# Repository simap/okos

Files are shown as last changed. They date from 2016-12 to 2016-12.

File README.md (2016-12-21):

One Kilobyte Operating System (OKOS)
================

Tiny OS for 1kB challenge.

Blurring the line between embedded system and general purpose computer. Inspired by all those wizardly tricks that brought computing to the masses on limited hardware.

OKOS is an operating system that allows the user to edit text or assembly source files code, assemble these into executables, and run their programs.

Features
---

* Runs on a PIC18f25k50, the MCU in the HaD SuperCon Badge!
* Display driver and API
	* Supports SSD1306 OLED display with 128x64 pixels over i2c, with the font included that is 32x8 characters.
	* Minimal 3x5 tiny font (remember original Apple ][ uppercase only font?)
	* Line buffered text drawing api (write whole row at a time)
	* Optional lowercase font, with descender support 3x5.5! But it takes 10 more bytes to support :(
	* Check out git history for a full ascii compatible font + display driver in less than 400 bytes.
* Filesystem (if you can call it that)
	* Actually just chopping 32k flash into 16 * 2k files.
	* 15 files available to user numbered 1-F. Can be either text files or programs.
* Touch keyboard
	* Chainable capacitive keyboard controller in 106.75 bytes.
	* Can scan up to 256 keys, though OKOS uses only 44 w/ 6 chained controllers.
	* Normal sized sized qwerty keyboard (keyboard and controller Eagle files included)
* Very basic command line interface lets you edit files, assemble them, and run programs
* Minimal instruction set assembler for the PIC MCU
	* What kind of OS doesn't let you write code?!?
	* Minimal, but workable, instruction set support.
	* Writes executable machine code into another file. Not interpreted!
* Visual Text Editor
	* Hopefully better than edlin
* Run
	* User program takes over
	* Core API available
	* User program interrupts supported (ISR vector depends on what program is running)
* OKOS is just ok because OKOS is just OK.

One Kilobyte Breakdown
-------

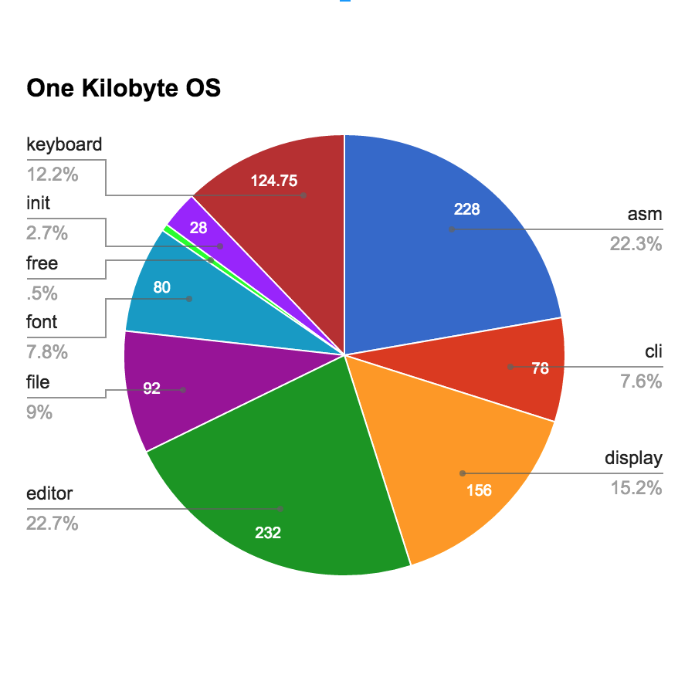
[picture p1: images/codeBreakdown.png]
Code usage by category


Visual Text Editor
================

Edit a text file with `e <file>` e.g. `e 1` to edit the text file `1`.

The current line will have an arrow in the left-side gutter. Arrow keys are not supported, but instead the keypad 8 (up) and 2 (down) keys are used for navigating. You can scroll through the file with these arrow keys.

The cursor is always at the end of the line. You can delete with backspace (including over newlines), or type to add more characters to a line. Pressing enter will append a newline.

Save the file with the `F1` key.

Assembler
================

Assemble a file with `a <source> <out>` e.g. `a 1 2` assembles source code in file `1` writing the executable to file `2`.

Minimal usable PIC instruction set.

3 character mnemonics to save space.

* `;` for comments, can be anywhere
* `.` on a line alone to end the file/parsing. **REQUIRED**

User ISR starts at offset **`0x04`** or. This gives you enough room to jump away at the start of your program.
Boilerplate program with an ISR:

```
bra 0012 ; jump past ISR
; insert your ISR code here
; ...
bra 000b ; execute a return
; at address 12. insert your code here
. ; EOF
```

User memory starts at address 0x3A, with the line buffer at 0x1A, anything before that is needed by the core API. If you don't use the API, feel free to reclaim this memory! Note that if you use ISRs, address 0x00 controls which file block the ISR jumps to.

Unfortunately, there wasn't enough room to support labels.

#### Instruction Set

| PIC instruction | short mnemonic | args | notes |
| --- | --- | --- | --- |
| bcf | bcf | f, b | 1 instruction |
| bsf | bsf | f, b | 1 instruction |
| btfsc | btc | f, b | 1 instruction |
| btfss | bts | f, b | 1 instruction |
| movlw | mvl | k | 1 instruction |
| movwf | mvw | f | 1 instruction |
| movf | mvf | f, d | 1 instruction |
| addwf | add | f, d | 1 instruction |
| andwf | and | f, d | 1 instruction |
| iorwf | ior | f, d | 1 instruction |
| xorwf | xor | f, d | 1 instruction |
| rlcf | rlc | f, d | 1 instruction |
| rrcf | rrc | f, d | 1 instruction |
| goto | bra | k | 2 instructions<br>target address is doubled. Think of them as instruction word addresses instead of byte addresses. File 1 starts at `0x400`|
| call | cal | k | 2 instructions. Same addressing as goto |
| return | - | - | NOT IMPLEMENTED<br>Use **`bra b`** |

**NOTE** return is not implemented, but a return instruction is placed at address 0x16 (word 0xb), jumping there will effect a return.

#### Core API

These API are available and potentially useful to user written programs.

| Routine | address | cal address | Notes |
| --- | --- | --- | --- |
| return_bra | 0x000016 | 000B | Use this to return. |
| oledDrawFlushLine | 0x00012c | 0096 | write up to 32 characters to 0x1A. Filled with spaces on return. | 
| readKey | 0x00015c | 00AE | Waits for keypress, returns character in WREG, also in 0x03. Blocks until key is pressed. You probably want to write something better in an ISR. |
| openFile | 0x0002d2 | 0169 | Sets up TBLPTR for reading/writing to the given file in WREG |
| fputc | 0x000294 | 014A | Writes a byte in WREG, flushing pages as needed |
| flushLastPage | 0x0002a2 | 0151 | If bit 0 in memory 0x01 is set, you need to call this once to flush the last page, since pages are only flushed by fputc in 64b increments. |

Running Programs
================

Once you've written and assembled an executable, you can run with with `r <file>` e.g. `r 2` to run file `2`.

Your program takes over until the computer is reset.

In main.asm, a define can be set to write an example program to flash. Both the assembler version and the text file are included.

Hardware
================

OKOS was written on and designed to run on the PIC MCU in the HaD SuperCon badge. The badge exposes a few GPIO, with i2c support. 

Originally OKOS was written with PS2 keyboard support, though later this was replaced with a capacitive touch keyboard so that all code could be accounted for. A define can be set to re-enable PS2 keyboard support without having to make your own keyboard hardware.

The keyboard is regular sized, and the solder joints were sanded down for a smooth surface before it was coated with polyurethane. It has a nice feel to it!

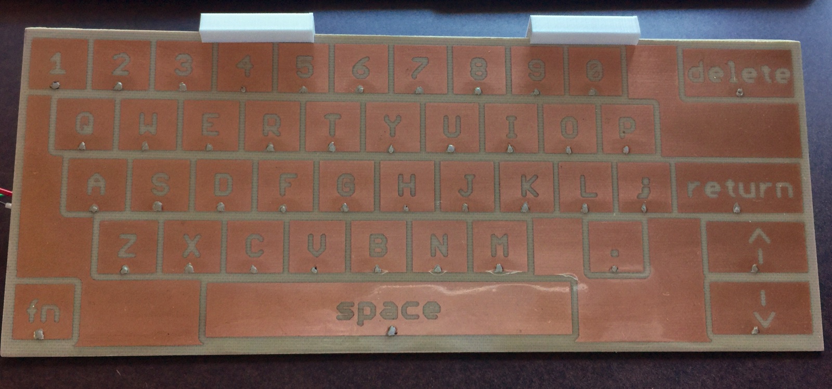
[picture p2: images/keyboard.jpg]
Touch qwerty keyboard


The capacitive touch keyboard is scanned with a handful of daisy chained pic16f1574 wired to a qwerty touch keyboard. Each runs exactly the same copy of code and scans 8 keys, passing messages from other controllers in the chain.

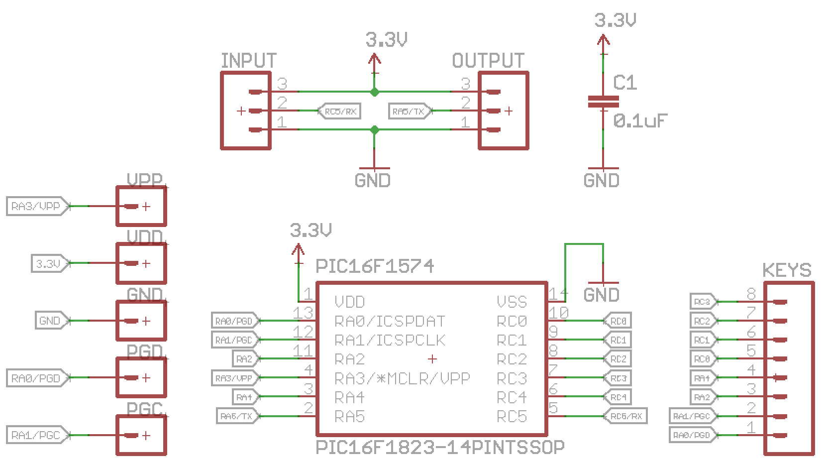
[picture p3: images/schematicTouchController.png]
Schematic of touch controller


6 of these controllers chained together make up the keyboard controller. 
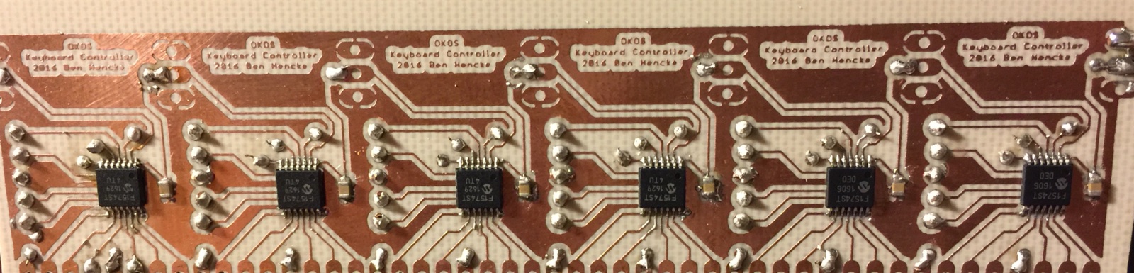
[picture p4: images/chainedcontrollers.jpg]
Assembled controller chain

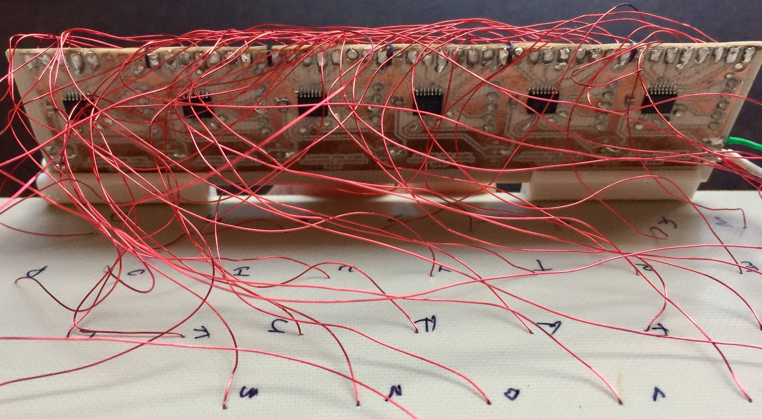
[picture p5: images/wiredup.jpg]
Controller chain attached to keyboard


There is also a board for placing the OLED display and doing level shifting to support PS2 keyboards. This connects to the expansion port on the badge.
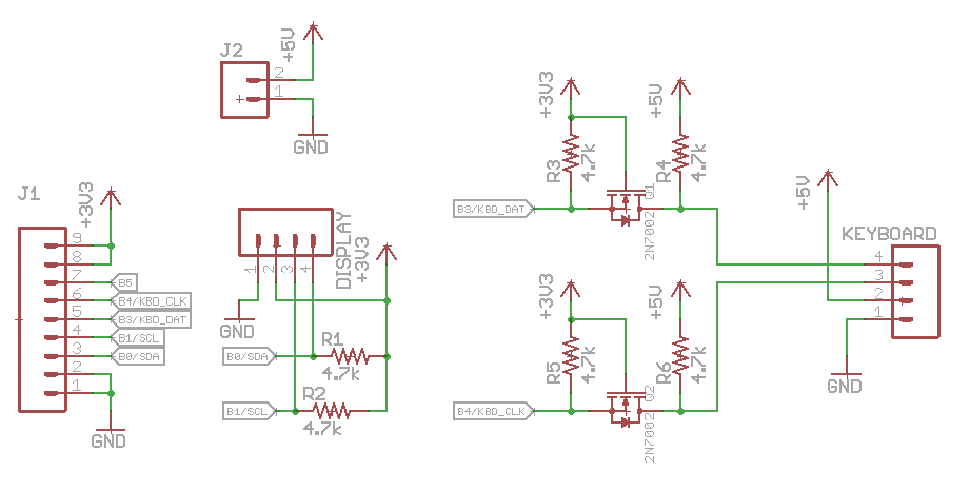
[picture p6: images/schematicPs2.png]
Schematic diagram


Notes
================

### Character set

Supports 0-9, a-z, period, semicolon, space, newline, esc, F1, backspace, Keypad 2,8,6

Maps directly to hex, such that 0x0 => '0', 0xa => 'A'.

### keyboard

Supports PS2 keyboards, decode scancodes into character set.

* simple protocol
* can ignore keyup. 
* ignore most special keys.

### filesystem

* pic18f25k50 has 32k flash. Split into 16 "files" of 2k each. file 0 (half of it anyway) contains OKOS.
* There wasn't enough space to do much else

### display

* the 128x64 oled needs very little setup.
* could get 10 lines of text (+ 4 pixels spare), but requires extra bit shifting. 8 lines of 8 pixels is easy w/ the displays 8 bit tall row x 128 segments.
* Each font face is 15 bits. To save space, only uppercase is supported, though the code can support lowercase and even use the 16th bit to shift down for lowercase descenders with 10 more bytes of code.
* Originally it rendered characters on the fly and send to display, but positioning and redraw was difficult. Now uses a line buffer and draws one row at a time, and is faster.

### MCU

Microchip PIC18f25k50

* uses 16-bit instruction words, and can store 2-8bit bytes per word easily.
* has 32k of flash, leaving plenty for filesystem
* Has almost enough RAM to fit entire 2k "file" into memory. 
* Also happens to be in the HaD SuperCon Badge.

### A Comment on Interrupts

First of all, I love interrupts. It's why I added some hooks that allow user programs to have ISRs at all.

However, when I went to write the i2c display stuff and the keyboard handling code, the ISR quickly consumed a lot of program space just saving and restoring registers. On top of that, the state machine, timers/timeouts, checking flags, etc. all took more space than I had.

1K Mapfile evidence
========

The main controller OS program code weighs in at 912 bytes. The keyboard controller is 106.75 bytes (61 14-bit instructions).

Main controller & OS
--------

[Full mapfile here](okos.X/dist/default/production/okos.X.production.map)

Note that configuraton fuses on the main PIC are located at `0x300000` and are not actually program flash, the programm usage calculation is flawed! Main controller program memory ends (and includes) address `0x00038f` - 912 bytes. Also `.cinit` is a bug/feature of MPLAB that could be removed with a custom linker file or by switching to absolute mode (as was done for the keyboard controller).

Here's the relevant bit from the mapfile:

```
                              Program Memory Usage 
                               Start         End      
                           ---------   ---------      
                            0x000000    0x00038f      
                            0x300000    0x300003      
                            0x300005    0x300006      
                            0x300008    0x30000d      
            924 out of 33048 program addresses used, program memory utilization is 2%
```

Keyboard controller
--------

[Full mapfile here](keyboard.X/dist/default/production/keyboard.X.production.map)

Note that configuraton fuses on the keyboard controller PIC are located at `0x008007` and are not actually program flash, the programm usage calculation is flawed! The program memory ends (and includes) address `0x00003c ` - 61 x 14-bit instructions or 854 bits = 106.75 bytes.

Here's the relevant bit from the mapfile:

```
                              Program Memory Usage 
                               Start         End      
                           ---------   ---------      
                            0x000000    0x00003c      
                            0x008007    0x008008      
            63 out of 4103 program addresses used, program memory utilization is 1%
```

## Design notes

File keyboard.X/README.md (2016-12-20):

OKOS Keyboard
==================

daisy chain pic16f1574 w/ uarts.
each chip reads 8 ADC touch pads
uart read, add 8, forward
arrange pads to align with character set

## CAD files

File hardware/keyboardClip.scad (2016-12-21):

keyboardW = 224;
keyboardH = 90;
controllerW = 126;
controllerH = 40;
extraH = 4;

gapW = (keyboardW-controllerW)/2;

difference() {
    translate([-keyboardW/2,0, controllerH + extraH])
    rotate([-asin((controllerH+extraH)/keyboardH),0,0]) 
    difference() {
        union() {
            rotate([asin((controllerH+extraH)/keyboardH),0,0]) 
            translate([gapW,-2.5,-9])
            cube([controllerW , 7, 14]);
        }
        #cube([keyboardW, keyboardH, 2], center=false);
    }

    translate([-controllerW/2,0,0])
    #cube([controllerW, 2, controllerH], center=false);
}

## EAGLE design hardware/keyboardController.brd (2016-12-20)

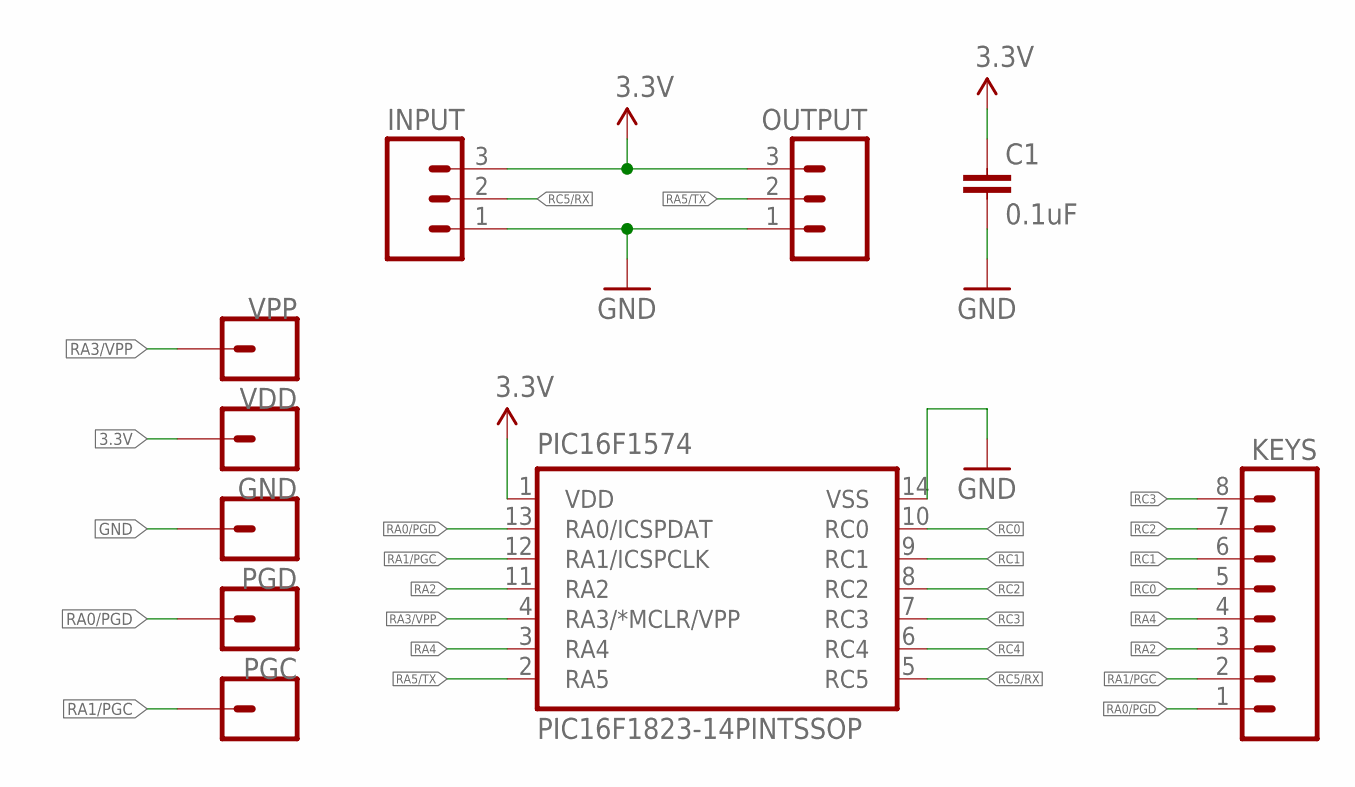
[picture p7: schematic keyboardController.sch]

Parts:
C1: 0.1uF; 0805
GND: M01PTH; 1X01
INPUT: M03LONGPADS; 1X03_LONGPADS
KEYS: M08LONGPADS; 1X08_LONGPADS
OUTPUT: M03LONGPADS; 1X03_LONGPADS
PGC: M01PTH; 1X01
PGD: M01PTH; 1X01
PIC16F1574: PIC16F1823-14PINTSSOP; TSSOP14
VDD: M01PTH; 1X01
VPP: M01PTH; 1X01

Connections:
3.3V: C1.1, INPUT.3, OUTPUT.3, PIC16F1574.1 (VDD), VDD.1
GND: C1.2, GND.1, INPUT.1, OUTPUT.1, PIC16F1574.14 (VSS)
RA0/PGD: KEYS.1, PGD.1, PIC16F1574.13 (RA0/ICSPDAT)
RA1/PGC: KEYS.2, PGC.1, PIC16F1574.12 (RA1/ICSPCLK)
RA2: KEYS.3, PIC16F1574.11 (RA2)
RA3/VPP: PIC16F1574.4 (RA3/*MCLR/VPP), VPP.1
RA4: KEYS.4, PIC16F1574.3 (RA4)
RA5/TX: OUTPUT.2, PIC16F1574.2 (RA5)
RC0: KEYS.5, PIC16F1574.10 (RC0)
RC1: KEYS.6, PIC16F1574.9 (RC1)
RC2: KEYS.7, PIC16F1574.8 (RC2)
RC3: KEYS.8, PIC16F1574.7 (RC3)
RC4: PIC16F1574.6 (RC4)
RC5/RX: INPUT.2, PIC16F1574.5 (RC5)

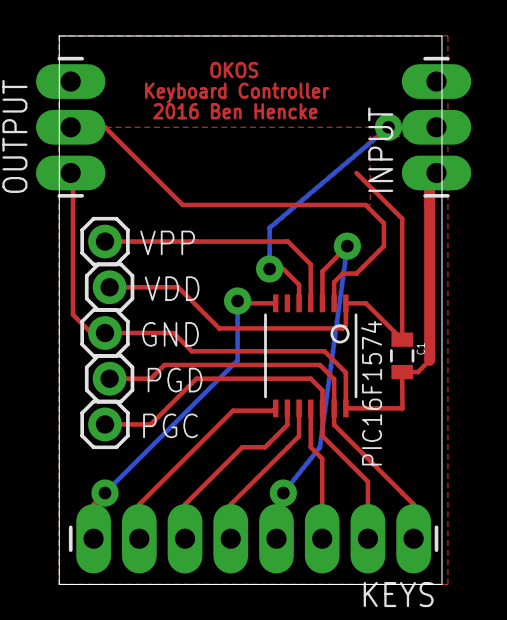
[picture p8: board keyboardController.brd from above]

Board: 2 copper layers, 21.3 x 30.5 mm, 10 parts (0 on the bottom side), 13 nets.

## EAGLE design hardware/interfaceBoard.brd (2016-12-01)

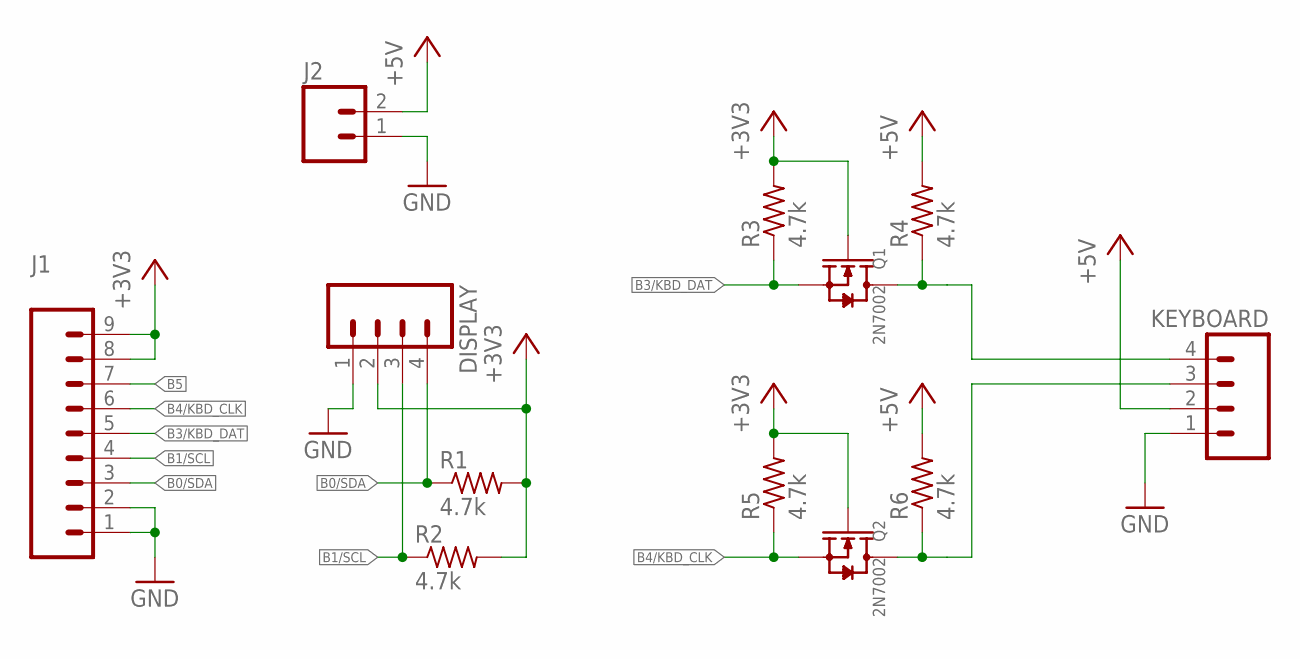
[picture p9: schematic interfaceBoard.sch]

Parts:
DISPLAY: M04LOCK_LONGPADS; 1X04_LOCK_LONGPADS
J1: M09LOCK-LONGPADS; 1X09_LOCK_LONGPADS
J2: M02PTH3; 1X02_LONGPADS
KEYBOARD: M04LOCK_LONGPADS; 1X04_LOCK_LONGPADS
Q1, Q2: 2N7002; SOT-23
R1, R2, R3, R4, R5, R6: 4.7k; R0805

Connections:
+3V3: DISPLAY.2, J1.8, J1.9, Q1.1 (G), Q2.1 (G), R1.2, R2.2, R3.2, R5.2
+5V: J2.2, KEYBOARD.2, R4.2, R6.2
B0/SDA: DISPLAY.4, J1.3, R1.1
B1/SCL: DISPLAY.3, J1.4, R2.1
B3/KBD_DAT: J1.5, Q1.2 (S), R3.1
B4/KBD_CLK: J1.6, Q2.2 (S), R5.1
B5: J1.7
GND: DISPLAY.1, J1.1, J1.2, J2.1, KEYBOARD.1
unnamed: KEYBOARD.4, Q1.3 (D), R4.1
unnamed: KEYBOARD.3, Q2.3 (D), R6.1

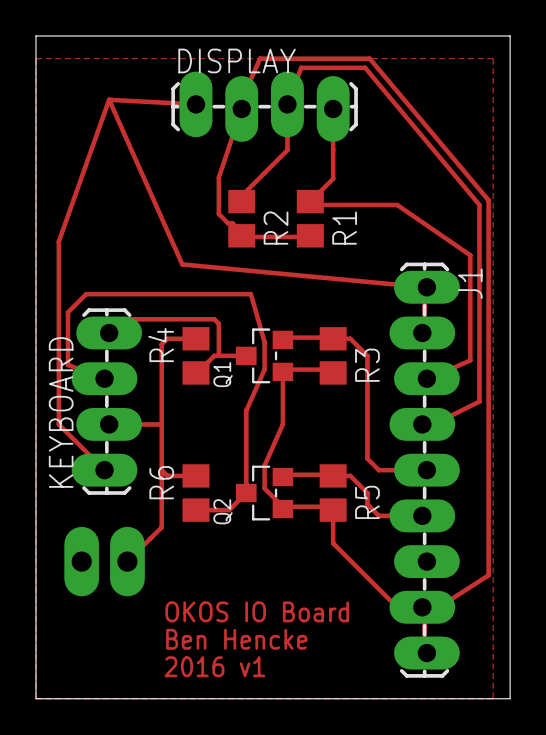
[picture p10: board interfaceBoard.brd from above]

Board: 2 copper layers, 26.3 x 36.8 mm, 12 parts (0 on the bottom side), 9 nets.

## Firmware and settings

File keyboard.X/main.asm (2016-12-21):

;*******************************************************************************
; OKOS Capacitive Touch Keyboard Controller
;
; 60 instructions x 14 bits = 105 bytes of program flash
; and 1 byte of memory
;
; A PS2 keyboard was easier for others to use, but was disqualifying
; for the 1k challege rules.
;
; So here's a keyboard controller that can read 8 capacitive touch keys.
; Since multiple microcontrollers running duplicate code is allowed, a bunch
; are linked together in a daisy chain to form a full keyboard.
; 
; Key press messages (0-7) are sent to the next controller, which is then 
; forwarded after 8 is added to the message. 
;
; In this way controllers don't need a configurable ID, and their address is set
; by their location in the chain. By careful key routing and placement of the 
; controllers in the chain, the desired character set can be achieved without
; any extra translation or lookup code.
;
; This would work with up to to 256 keys using 32 controllers.
;
; NOTE: I switched to absolute linker mode to avoid the .cinit bullshit
;*******************************************************************************
    
    radix dec
#include "p16F1574.inc"
    
#define CALIBRATE_MODE 0

; adjust these to fit the capacitive touch pad
    
;1 key - a9/5a
;space 9a/51
    
#define TOUCH_THRESHOLD_RELEASE 0x87
#define TOUCH_THRESHOLD_PRESS 0x77
    
; CONFIG1
; __config 0xFF84
 __CONFIG _CONFIG1, _FOSC_INTOSC & _WDTE_OFF & _PWRTE_OFF & _MCLRE_OFF & _CP_OFF & _BOREN_ON & _CLKOUTEN_OFF
; CONFIG2
; __config 0xFFFB
 __CONFIG _CONFIG2, _WRT_OFF & _PPS1WAY_OFF & _PLLEN_ON & _STVREN_ON & _BORV_LO & _LPBOREN_OFF & _LVP_OFF

 
    CBLOCK  0x70 ; common ram
	adconNext
    ENDC
 
;*******************************************************************************
; Reset vector
;*******************************************************************************
    
    ORG     0x0000 ; processor reset vector
reset_init:
    ;bank3 reg setup
    movlb 3
    ;set up uart
    bsf RCSTA, SPEN
    bsf TXSTA, TXEN
    ;right after reset clock is 500khz, BRG16=0, BRGH=0, SPBRGL=0, SPBRGH=0, which is 7812.5 baud
    ;even at the far edge, it should take a character ~8ms to propagate 
    ;setting either BRG16 or BRGH will bring that to 31250 baud. setting both will get 125000 baud.
    goto init

;*******************************************************************************
; Interrupt vector
;*******************************************************************************

    ORG     0x0004 ; interrupt vector location
isr:
    ;the only interrupt is the serial port forward
    movlb 3; uart stuff in bank 3
    ;when we receive a byte, add 8 and pass it along.
    ;this makes each chip in the sequence have a unique id that is sequential on top of the key pressed
    movf RCREG, w
    addlw .8
    
;waits for TRMT flag, sends byte in WREG
sendByte:
    bcf INTCON, GIE ; HACK during ISR this does nothing, as a subroutine this prevents ISR TXREG collision
    ;wait for transmit to finish
waitTrmt:
    btfss TXSTA, TRMT
    goto waitTrmt
    movwf TXREG
    ; HACK during ISR retfie is normal, as a subroutine this returns and re-enables GIE.
    ; as subroutine this also corrupts BSR, WREG, and PCLATH because the 
    ; shadow register may not be initialized
    retfie 
    
;*******************************************************************************
; Main code
;*******************************************************************************

init:
    bsf RCSTA, CREN ; continued from reset vector, already in bank 3

    ;bank2 reg setup
    movlb 2
    ;after reset all analog pins are in analog mode, tris set for input, no need to repeat that
    ;using DAC to charge holding cap
    bsf DACCON0, DACEN
    comf DACCON1, f ; set to all 1s
    clrf LATA
    clrf LATC
    
    ;set uart pins
    ;RC5 defaults to RX, which is nice
    ;Of all the ports, RA5 and RC4 can be an output, and not used for analog
    ;use RA5 for symmetry
    ;RxyPPS = 1001 = TX
    movlb .29
    movlw b'00001001'
    movwf RA5PPS
    
    movlb 1 ; bank 1 has TRISx, PIE1, ADC stuff, the only bank we'll ever need
    ;enable interrupts for serial forwards
    bsf INTCON, PEIE
    bsf INTCON, GIE
    ;enable RX interrupts
    bsf PIE1, RCIE
    
scanInit:    
    ;set up adconNext, with CHS = 00000, GO = 0, ADON = 1, also happens to be 1
    movlw 1
    movwf adconNext
    
scanLoop:
    
#if CALIBRATE_MODE
    ;in calibrate mode, send each key and adc value
    ;send current key to uart
    movlb 3; uart stuff in bank 3
    ;get key from CHS by shifting right twice (gets rid of ADON too)
    lsrf adconNext, w
    lsrf WREG, w
    call sendByte
    clrf PCLATH
    movlb 1 ; back to bank 1
    call sampleButton
    movlb 3; uart stuff in bank 3
    call sendByte
    clrf PCLATH
    movlb 1 ; back to bank 1
    goto keyPressedDone ; skip press detection stuff
#endif
    
    ;regular run mode, check current key and check it against threshold, and
    ;send key if touched, then wait for release
    call sampleButton
    sublw TOUCH_THRESHOLD_PRESS
    btfss STATUS, C ;a value lower than threshold indiates high capacitance, a touch
    goto keyPressedDone
    
    ;send key to uart
    movlb 3; uart stuff in bank 3
    ;get key from CHS by shifting right twice (gets rid of ADON too)
    lsrf adconNext, w
    lsrf WREG, w
    call sendByte
    clrf PCLATH ; fix corrupted PCLATH so call still works
    movlb 1 ; back to bank 1
    
keyPressedLoop:
    ;wait for key up
    ;this was much simpler (less code) than maintaining state and handling multiple
    ;simultaneous keypresses.
    call sampleButton
    sublw TOUCH_THRESHOLD_RELEASE
    btfsc STATUS, C ;a value higher than threshold indiates low capacitance, no touch
    goto keyPressedLoop
    
keyPressedDone:
    ;after each loop increment to next CHS
    ;remember CHS is 2 bits left in ADCON0
    movlw 0x4
    addwf adconNext, f
    ;restart loop when CHS == 8
    btfsc adconNext, 5 
    goto scanInit
    goto scanLoop
    
sampleButton:
    ;set ADC channel to the DAC (set to VDD) to charge the sample and hold cap
    ; x | CHS = 11110 (DAC) | GO = 0 | ADON = 1
    movlw b'01111001'
    movwf ADCON0
    
    
    ;at 500khz, each instruction takes 8us, so we probably don't need extra wait for TACQ
    
    ;set all touch input pins low to ground the touch capacitor
    ;don't mess with ra5/rc5, as those are tx/rx
    movlw b'11100000'
    andwf TRISA, f
    andwf TRISC, f
    
    ;set back to inputs
    movlw b'00011111'
    iorwf TRISA, f
    iorwf TRISC, f
    
    ;set ADCON0 CHS to the pin to check, this connects the charged sample and hold cap
    ;with the discharged touch cap. 
    movf adconNext, w
    movwf ADCON0
    
    ;at 500khz, each instruction takes 8us, so we probably don't need extra wait for TACQ
    
    ;sample the ADC
    bsf ADCON0, GO
    ;wait for done
waitAdcDone:
    btfsc ADCON0, GO
    goto waitAdcDone
    
    movf ADRESH, w ; load result in w for caller
    return
    
endOfProgram:

    END

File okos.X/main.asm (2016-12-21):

;*******************************************************************************
; OKOS - One Kilobyte Operating System
;
; A user operating system in 1kB.
; OKOS us just OK because OKOS is just OK.
; 
; Hacked together using the Hackaday Superconference Badge
;*******************************************************************************
#include p18f25k50.inc

#define INCLUDE_EXAMPLE_FILES 0
;set this to support a PS2 keyboard instead of the custom capacitive touch keyboard
#define PS2_KEYBOARD 0

#include <charset.h>
    
 config PLLSEL = PLL3X      ; 3x clock multiplier
 config CFGPLLEN = ON       ; PLL Enabled
 config CPUDIV = NOCLKDIV   ; 1:1 mode
 config LS48MHZ = SYS48X8   ; System clock at 48 MHz, USB clock divider is set to 8
 config FOSC = INTOSCIO     ; Internal oscillator
 config PCLKEN = OFF        ; Primary oscillator disabled
 config FCMEN = OFF         ; Fail-Safe Clock Monitor disabled
 config IESO = OFF          ; Oscillator Switchover mode disabled
 config nPWRTEN = ON        ; Power up timer enabled
 config BOREN = OFF         ; BOR disabled
 config nLPBOR = OFF        ; Low-Power Brown-out Reset disabled
 config WDTEN = OFF         ; WDT disabled in hardware (SWDTEN ignored)
 config CCP2MX = RC1        ; CCP2 input/output is multiplexed with RC1
 config PBADEN = OFF        ; PORTB<5:0> pins are configured as digital I/O on Reset
 config MCLRE = ON          ; MCLR pin enabled; RE3 input disabled
 config STVREN = OFF        ; Stack full/underflow will not cause Reset
 config LVP = OFF           ; Single-Supply ICSP disabled
 config XINST = OFF         ; Instruction set extension and Indexed Addressing mode disabled
; config DEBUG = ON         ; Bkgnd debugger disabled, RB6 and RB7 configured as gp I/O pins
 config ICPRT = OFF
 config CP0 = OFF           ; Block 0 is not code-protected
 config CP1 = OFF           ; Block 1 is not code-protected
 config CPB = OFF           ; Boot block is not code-protected
 config CPD = OFF           ; Data EEPROM is not code-protected
 config WRT0 = OFF          ; Block 0 (0800-1FFFh) is not write-protected
 config WRT1 = OFF          ; Block 1 (2000-3FFFh) is not write-protected
 config WRTC = OFF          ; Configuration registers (300000-3000FFh) are not write-protected
 config WRTB = OFF          ; Boot block (0000-7FFh) is not write-protected
 config WRTD = OFF          ; Data EEPROM is not write-protected
 config EBTR0 = OFF         ; Block 0 is not protected from table reads executed in other blocks
 config EBTRB = OFF         ; Boot block is not protected from table reads executed in other blocks

;*******************************************************************************
; Memory allocations
;*******************************************************************************

#include <memory.asm>

;*******************************************************************************
; Reset Vector
;*******************************************************************************

RES_VECT  CODE    0x0000            ; processor reset vector
resetvector:
    clrf flags
    clrf cursorY
    bsf OSCCON, IRCF2 ; set for 16Mhz x3 = 48mhz
    bra    START                   ; go to beginning of program

;*******************************************************************************
; Interrupt Vector
; OKOS doesn't use ISRs, but supports user ISRS offset by 4.
; The code to support that is hidden in the area usually occupied by the high
; priority interrupt vector.
;*******************************************************************************

HIGHISR       CODE    0x0008
       ; don't suport high priority interrupts, instead, hide some code here that calls the user's ISR
userIsr:
    movf currentFile, w ;load current file and multiple by 8 to get it's 2k offset
    rlncf WREG, f
    rlncf WREG, f
    rlncf WREG, f
    movwf PCLATH
    movlw .4 ; user ISR vector. TODO offset by 1 page (64 bytes) to reserve some room for file metadata.
    movwf PCL
return_bra: ; HACK: user can jump to this location in order to effect a return from subroutine (instead of supporting a 'return' mnemonic)
    return

LOWISR       CODE    0x0018
isr:
    ;TODO check for running program, call its ISR offset
    ;interrupts won't be enabled unless a user program is run and enables them
    ;user's ISR is responsible for saving and restoring registers used beyond WREG, STATUS, and BSR (done automatically)
    ;user's ISR must then return (retfie is not supported by the assembler)
    
    rcall userIsr
    RETFIE FAST ; restores STATUS, WREG, BSR. only usable if high priority interrupts are not enabled

;*******************************************************************************
; Table Data
; tables are put in the first page of flash to make access easier
; this is placed just after the ISR code
;*******************************************************************************

TABLE_DATA CODE 0x1c
     #include <font.asm>
#if PS2_KEYBOARD
     #include <keycodesPs2.asm>
#endif
     #include <opcodes.asm>

;*******************************************************************************
; MAIN PROGRAM
;*******************************************************************************    
    
MAIN_PROG CODE 
    #include <oled.asm>
#if PS2_KEYBOARD
    #include <keyboardPs2.asm>
#else
    #include <keyboardTouch.asm>
#endif
    #include <editor.asm>
    #include <files.asm>
    #include <assembler.asm>

START
    
    
;    #include <testassembler.asm>

initKeyboard:
    keyboardInit
initOled:
    oledInit

;    #include <testkeyboard.asm>
    
    #include <cli.asm>
    
#if INCLUDE_EXAMPLE_FILES
    #include <examplefiles.asm>
#endif
    
endofmain
    end
    

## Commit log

2016-11-19 initial working i2c display
2016-11-23 switch to row based output, add newline, tweak init code
2016-11-26 support drawing a cursor (or line), keep track of column
2016-11-27 move some init stuff to reset vector
    [main.asm]
2016-11-28 insert, move up/down
2016-11-28 assembler lookup table
2016-11-28 cut upper/lowercase support, custom charset. WIP
2016-12-01 assembler working
2016-12-01 fix charset issues, trim more init code from oled
    [oled.asm]
2016-12-01 interface pcb
    [interfaceBoard.brd, interfaceBoard.sch]
2016-12-04 editor can view files, scroll around WIP. switch up keyboard codes a bit
2016-12-04 working editor, switch write method to use buffered line
    this saves code, and is faster. no start+stop per character
2016-12-05 it works! map file shows 1022 bytes
    took out the clock hold on keyboard
    fixed some memory pointer issues
    even with 2 lost for cinit
    [main.asm]
2016-12-07 comment about interrupts
2016-12-20 add okos keyboard code and boards
    [keyboard.brd, keyboard.sch, keyboardController.brd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]
2016-12-21 update okos to use touch keyboard
    [keyboardClip.scad]

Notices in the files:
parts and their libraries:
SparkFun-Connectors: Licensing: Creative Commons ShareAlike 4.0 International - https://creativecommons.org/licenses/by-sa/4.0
